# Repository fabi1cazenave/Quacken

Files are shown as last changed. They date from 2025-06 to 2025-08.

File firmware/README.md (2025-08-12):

# Firmware

## Keyberon

This directory contains our Keyberon driver. It’s been tested with a SparkFun
Pro Micro RP2040 and should be easy to adapt to other controllers.

To flash your keyboard, get in UF2 bootloader mode and do:

```rust
cargo run
```

If `elf2uf2-rs` does not work “as is” (see [this issue][1]), you can install a
patched version with:

```bash
cargo install --git https://github.com/StripedMonkey/elf2uf2-rs.git#c1638b9
```

## ZMK

[There is a ZMK Configuration on a dedicated repo][2].
It will be moved here when [this PR][3] gets merged.

[1]: https://github.com/JoNil/elf2uf2-rs/pull/41
[2]: https://github.com/Nuclear-Squid/zmk-keyboard-quacken
[3]: https://github.com/zmkfirmware/zmk/pull/2975

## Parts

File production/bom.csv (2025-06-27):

Designator | Footprint | Quantity | Value | LCSC Part #
D1, D10, D11, D12, D13, D14, D15, D16, D17, D18, D19, D2, D20, D21, D22, D23, D24, D25, D26, D27, D28, D29, D3, D30, D31, D32, D33, D34, D35, D36, D37, D38, D39, D4, D40, D41, D42, D5, D6, D7, D8, D9 | D_SOD-323 | 42

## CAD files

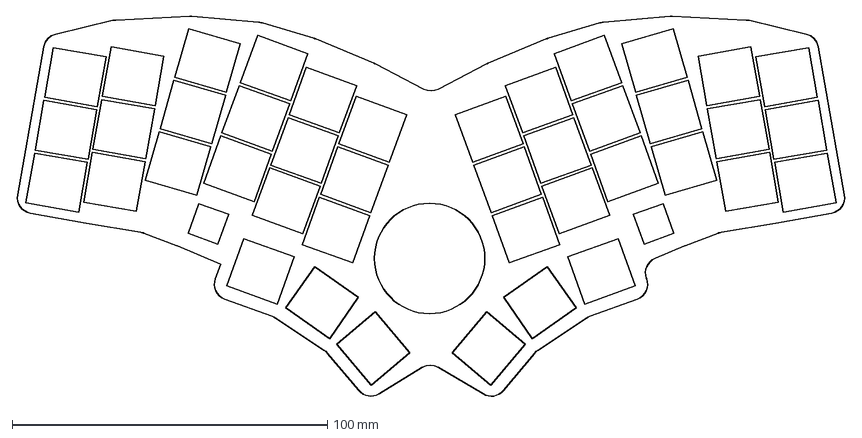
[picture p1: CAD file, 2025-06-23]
output/outlines/combo.dxf
263.0 x 121.1 mm

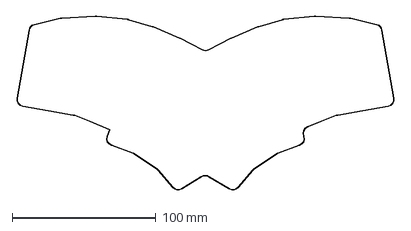
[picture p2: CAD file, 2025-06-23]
output/outlines/board.dxf
263.0 x 121.1 mm

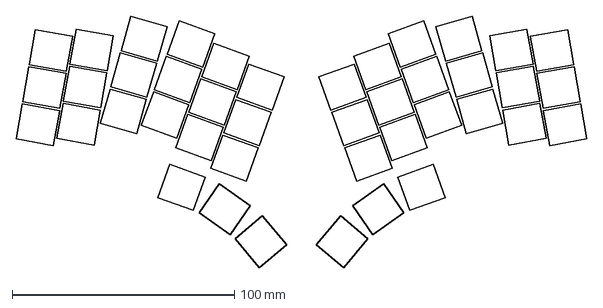
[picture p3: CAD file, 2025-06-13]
output/outlines/keys.dxf
256.9 x 113.0 mm

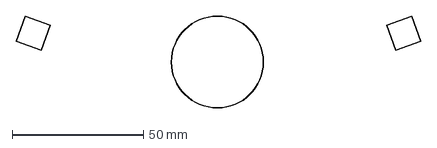
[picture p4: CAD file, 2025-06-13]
output/outlines/electronics.dxf
154.0 x 35.0 mm

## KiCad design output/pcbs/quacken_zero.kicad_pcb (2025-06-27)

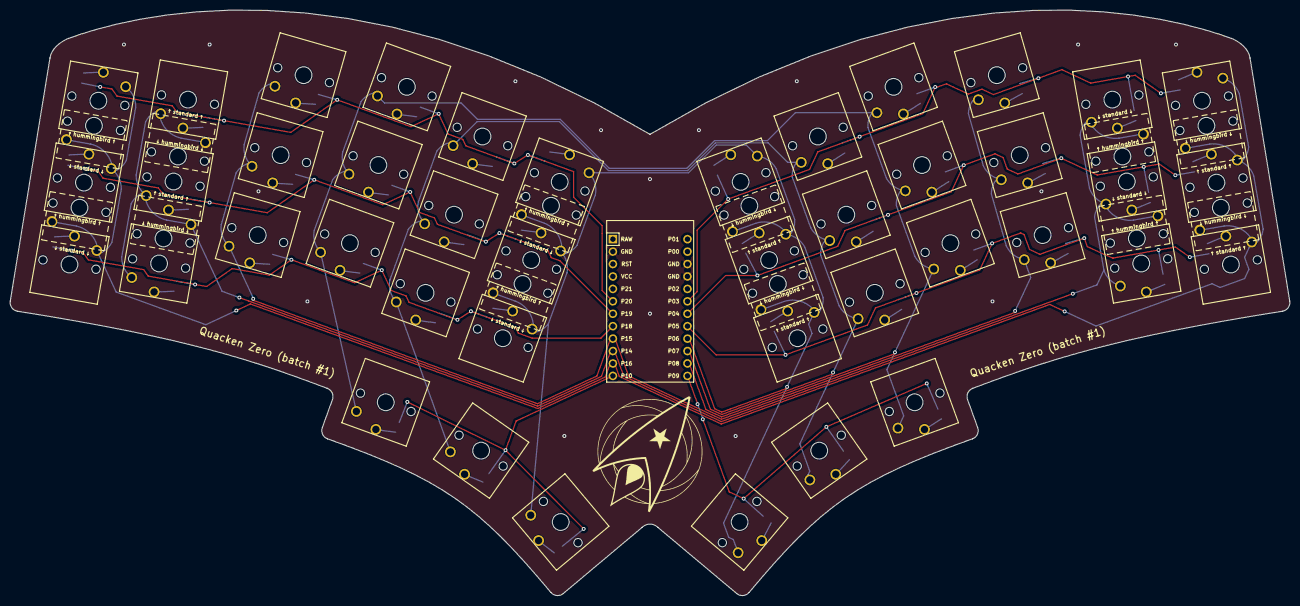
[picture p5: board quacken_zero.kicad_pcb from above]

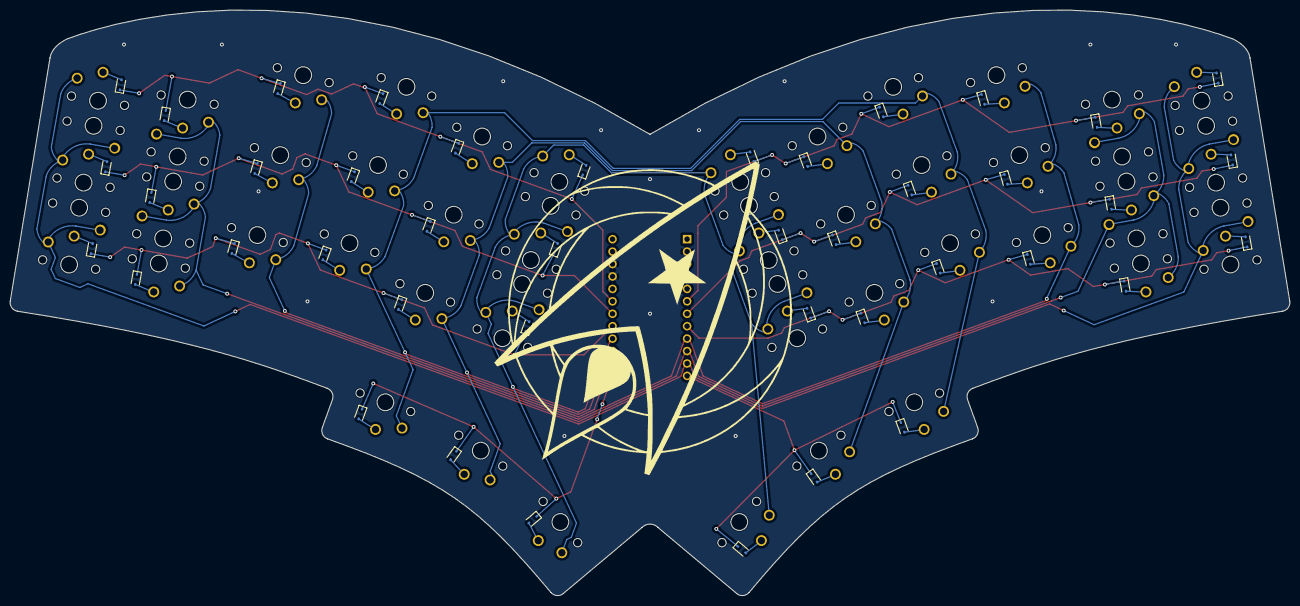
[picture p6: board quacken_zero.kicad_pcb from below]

Board: 2 copper layers, 261.5 x 119.6 mm, 85 parts (42 on the bottom side), 57 nets.

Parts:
D1, D2, D3, D4, D5, D6, D7, D8, D9, D10, D11, D12, D13, D14, D15, D16, D17, D18, D19, D20, D21, D22, D23, D24, D25, D26, D27, D28, D29, D30, D31, D32, D33, D34, D35, D36, D37, D38, D39, D40, D41, D42: D_SOD-323
MCU1: ProMicro
S1, S2, S3, S4, S5, S6, S7, S8, S9, S10, S11, S12, S13, S14, S15, S16, S17, S18, S19, S20, S21, S22, S23, S24, S25, S26, S27, S28, S29, S30, S31, S32, S33, S34, S35, S36, S37, S38, S39, S40, S41, S42: PG1350

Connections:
GND: MCU1.2, MCU1.15, MCU1.16
P3: D18.1, D21.1, D24.1, D27.1, D39.1, D42.1, MCU1.18
P4: D17.1, D20.1, D23.1, D26.1, D38.1, D41.1, MCU1.19
P5: D16.1, D19.1, D22.1, D25.1, D37.1, D40.1, MCU1.20
P6: MCU1.21, S15.1, S30.1, S34.1, S34.3, S35.1, S35.3, S36.1, S40.1, S40.3, S41.1, S41.3, S42.1
P7: MCU1.22, S10.1, S11.1, S12.1, S14.1, S25.1, S26.1, S27.1, S29.1
P8: MCU1.23, S7.1, S8.1, S9.1, S13.1, S22.1, S23.1, S24.1, S28.1
P9: D28.1, D29.1, D30.1, MCU1.24
P10: D13.1, D14.1, D15.1, MCU1.12
P14: MCU1.10, S1.1, S2.1, S2.3, S3.1, S3.3, S16.1, S17.1, S17.3, S18.1, S18.3
P15: MCU1.9, S4.1, S5.1, S6.1, S19.1, S20.1, S21.1
P16: MCU1.11, S31.1, S31.3, S32.1, S32.3, S33.1, S37.1, S37.3, S38.1, S38.3, S39.1
P18: D1.1, D4.1, D7.1, D10.1, D31.1, D34.1, MCU1.8
P19: D2.1, D5.1, D8.1, D11.1, D32.1, D35.1, MCU1.7
P20: D3.1, D6.1, D9.1, D12.1, D33.1, D36.1, MCU1.6
comfy_default: D14.2, S14.2
index_bottom: D10.2, S10.2
index_home: D11.2, S11.2
index_top: D12.2, S12.2
inner_bottom: D34.2, S34.2
inner_home: D35.2, S35.2
inner_top: D36.2, S36.2
middle_bottom: D7.2, S7.2
middle_home: D8.2, S8.2
middle_top: D9.2, S9.2
mirror_comfy_default: D29.2, S29.2
mirror_index_bottom: D25.2, S25.2
mirror_index_home: D26.2, S26.2
mirror_index_top: D27.2, S27.2
mirror_inner_bottom: D40.2, S40.2
mirror_inner_home: D41.2, S41.2
mirror_inner_top: D42.2, S42.2
mirror_middle_bottom: D22.2, S22.2
mirror_middle_home: D23.2, S23.2
mirror_middle_top: D24.2, S24.2
mirror_outer_bottom: D37.2, S37.2
mirror_outer_home: D38.2, S38.2
mirror_outer_top: D39.2, S39.2
mirror_pinky_bottom: D16.2, S16.2
mirror_pinky_home: D17.2, S17.2
mirror_pinky_top: D18.2, S18.2
mirror_reachy_default: D30.2, S30.2
mirror_ring_bottom: D19.2, S19.2
mirror_ring_home: D20.2, S20.2
mirror_ring_top: D21.2, S21.2
mirror_tucky_default: D28.2, S28.2
outer_bottom: D31.2, S31.2
outer_home: D32.2, S32.2
outer_top: D33.2, S33.2
pinky_bottom: D1.2, S1.2
pinky_home: D2.2, S2.2
pinky_top: D3.2, S3.2
reachy_default: D15.2, S15.2
ring_bottom: D4.2, S4.2
ring_home: D5.2, S5.2
ring_top: D6.2, S6.2
tucky_default: D13.2, S13.2

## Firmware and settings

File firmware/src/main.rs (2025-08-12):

#![no_std]
#![no_main]

mod layout; // 3*6 key layout
mod zero;   // QuackenZero-specific matrix scanning

// set the panic handler
use panic_halt as _;

#[unsafe(link_section = ".boot2")]
#[used]
pub static BOOT2: [u8; 256] = rp2040_boot2::BOOT_LOADER_W25Q080;

#[rtic::app(
    device = rp2040_hal::pac,
    peripherals = true,
    dispatchers = [PIO0_IRQ_0, PIO0_IRQ_1, PIO1_IRQ_0]
)]
mod app {
    use crate::layout::{self as kb_layout, QuackenLayout};
    use crate::zero::QuackenZeroMatrix;

    use core::convert::Infallible;

    use cortex_m::delay::Delay;

    use rp2040_hal::{
        self,
        Clock,
        clocks::init_clocks_and_plls,
        fugit::MicrosDurationU32,
        pac::CorePeripherals,
        gpio::Pins,
        sio::Sio,
        timer::{ Alarm, Alarm0, Timer },
        usb::UsbBus,
        watchdog::Watchdog,
    };

    use keyberon::{
        debounce::Debouncer,
        key_code::KbHidReport,
        layout::Layout,
    };

    use usb_device::{
        prelude::UsbDeviceState,
        class_prelude::UsbBusAllocator,
        // HACK: import the UsbClass trait, but still allow to use its name for a type later
        class::UsbClass as _,
    };

    type UsbClass = keyberon::Class<'static, UsbBus, ()>;
    type UsbDevice = usb_device::device::UsbDevice<'static, UsbBus>;

    trait ResultExt<T> {
        fn get(self) -> T;
    }
    impl<T> ResultExt<T> for Result<T, Infallible> {
        fn get(self) -> T {
            match self {
                Ok(v) => v,
                Err(e) => match e {},
            }
        }
    }

    // Fun fact: the keyboard is invisible to `lsusb`
    // if the scan time is set to 10_000 us or above.
    const SCAN_TIME_US:          u32 = 1_000;
    const WATCHDOG_TIME_US:      u32 = 10_000;
    const EXTERNAL_XTAL_FREQ_HZ: u32 = 12_000_000;

    #[shared]
    struct Shared {
        usb_dev: UsbDevice,
        usb_class: UsbClass,
        alarm: Alarm0,
        #[lock_free]
        watchdog: Watchdog,
    }

    #[local]
    struct Local {
        matrix: QuackenZeroMatrix,
        layout: QuackenLayout,
        debouncer: Debouncer<[[bool; kb_layout::COLS]; kb_layout::ROWS]>,
        delay: Delay,
        timer: Timer,
    }

    #[init(local = [bus: Option<UsbBusAllocator<UsbBus>> = None])]
    fn init(c: init::Context) -> (Shared, Local) {
        // https://github.com/rp-rs/rp-hal/blob/main/rp2040-hal-examples/src/bin/gpio_in_out.rs
        let mut resets = c.device.RESETS;
        let sio = Sio::new(c.device.SIO);
        let pins = Pins::new(
            c.device.IO_BANK0,
            c.device.PADS_BANK0,
            sio.gpio_bank0,
            &mut resets,
        );

        let mut watchdog = Watchdog::new(c.device.WATCHDOG);
        watchdog.pause_on_debug(false);

        let clocks = init_clocks_and_plls(
            EXTERNAL_XTAL_FREQ_HZ,
            c.device.XOSC,
            c.device.CLOCKS,
            c.device.PLL_SYS,
            c.device.PLL_USB,
            &mut resets,
            &mut watchdog,
        )
        .unwrap();

        let core = unsafe { CorePeripherals::steal() };
        let delay = Delay::new(core.SYST, clocks.system_clock.freq().to_Hz());

        let mut timer = Timer::new(c.device.TIMER, &mut resets, &clocks);
        let mut alarm = timer.alarm_0().unwrap();
        alarm
            .schedule(MicrosDurationU32::micros(SCAN_TIME_US))
            .expect("Couldn’t schedule matrix scan, kb is effectively bricked");
        alarm.enable_interrupt();

        let usb = UsbBus::new(
            c.device.USBCTRL_REGS,
            c.device.USBCTRL_DPRAM,
            clocks.usb_clock,
            true,
            &mut resets,
        );

        *c.local.bus = Some(UsbBusAllocator::new(usb));
        let usb_bus = c.local.bus.as_ref().unwrap();

        let usb_class = keyberon::new_class(usb_bus, ());
        let usb_dev = keyberon::new_device(usb_bus);

        watchdog.start(MicrosDurationU32::micros(WATCHDOG_TIME_US));

        let Ok(matrix) = QuackenZeroMatrix::new_sparkfun_rp2040(pins);

        (
            Shared {
                usb_dev,
                usb_class,
                alarm,
                watchdog,
            },
            Local {
                matrix,
                layout: Layout::new(&kb_layout::LAYERS),
                debouncer: Debouncer::new(
                    [[false; kb_layout::COLS]; kb_layout::ROWS],
                    [[false; kb_layout::COLS]; kb_layout::ROWS],
                    5
                ),
                delay,
                timer,
            },
        )
    }

    // USB events (polling)
    #[task(
        binds = USBCTRL_IRQ,
        priority = 4,
        shared = [usb_dev, usb_class]
    )]
    fn usb_rx(c: usb_rx::Context) {
        let usb = c.shared.usb_dev;
        let kb = c.shared.usb_class;
        (usb, kb).lock(|usb, kb| {
            if usb.poll(&mut [kb]) {
                kb.poll();
            }
        });
    }

    // keyboard events (timer)
    #[task(
        binds = TIMER_IRQ_0,
        priority = 1,
        local = [matrix, layout, debouncer, delay, timer],
        shared = [alarm, watchdog, usb_dev, usb_class],
    )]
    fn process_kbd_events(mut c: process_kbd_events::Context) {
        c.shared.alarm.lock(|a| {
            a.clear_interrupt();
            a.schedule(MicrosDurationU32::micros(SCAN_TIME_US))
                .expect("Couldn’t schedule matrix scan, kb is effectively bricked");
            a.enable_interrupt();
        });

        c.shared.watchdog.feed();

        let delay_1us = || { c.local.delay.delay_us(1) };
        for event in c.local.debouncer.events(c.local.matrix.get_with_delay(delay_1us).get()) {
            c.local.layout.event(event);
        }

        c.local.layout.tick();

        if c.shared.usb_dev.lock(|d| d.state()) != UsbDeviceState::Configured {
            return;
        }

        let report: KbHidReport = c.local.layout.keycodes().collect();
        if !c
            .shared
            .usb_class
            .lock(|k| k.device_mut().set_keyboard_report(report.clone()))
        {
            return;
        }

        while let Ok(0) = c.shared.usb_class.lock(|k| k.write(report.as_bytes())) {}
    }
}

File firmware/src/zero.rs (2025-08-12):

/**
The Quacken Zero physical matrix misses Keyberon's expectations on 2 points:
 - it doesn't match the logical layout
 - it is set col2row with pull-down inputs

Besides, the ProMicro GPIO pinout used by Ergogen and ZMK rely on the ProMicro Atmel IDs
-- but rb2040_hal, obviously, does not. So we need a Matrix factory for every ProMicro controller.

    .   +----USB----+               +----USB----+            D+ +----USB----+ D-
    . 1 |           | RAW         0 |           | RAW         1 |           | RAW
    . 0 |           | GND         1 |           | GND         0 |           | GND
    GND | SparkFun  | RST       GND | SparkFun  | RST       GND | Adafruit  | RST
    GND |   Atmel   | VCC       GND |  rp2040   | VCC       GND |  kb2040   | VCC
    . 2 |           | 21          2 |           | 29          2 |           | 29
    . 3 |           | 20          3 |           | 28          3 |           | 28
    . 4 |           | 19          4 |           | 27          4 |           | 27
    . 5 |           | 18          5 |           | 26          5 |           | 26
    . 6 |           | 15          6 |           | 22          6 |           | 18
    . 7 |           | 14          7 |           | 20          7 |           | 20
    . 8 |           | 16          8 |           | 23          8 |           | 19
    . 9 |___________| 10          9 |___________| 21          9 |___________| 10
**/

// The logical layout is a 12×4 matrix: 3×6 + 3 thumb keys for each hand.
// Ergogen has generated an 8*6 matrix rather than a 12×4 one, in order to save two pins:
// the two halves are stacked onto one anather. So here’s q quick helper to work around that.

use crate::layout;
const MATRIX_COLS: usize = 6;
const MATRIX_ROWS: usize = 8;

// this could be done with keyberon's debouncer (`transform` function)
fn matrix_to_layout(row: usize, col: usize) -> (usize, usize) {
    if row >= layout::ROWS {
        (row - layout::ROWS, layout::COLS - col - 1)
    } else {
        (row, col)
    }
}

// Keyberon expects rows to bo outputs, and columns to be pull-up inputs. ("row2col" on ZMK)
// On the Quacken Zero, rows are pull-down inputs and columns are outputs. ("col2row" on ZMK)
// So here's a `Col2RowMatrix` type to implement this.

// rp2040 implementations of the embedded_hal::digital::InputPin,OutputPin} traits
use rp2040_hal::gpio;
use embedded_hal::digital::{InputPin, OutputPin};
type KbInputPin  = gpio::Pin<gpio::DynPinId, gpio::FunctionSioInput,  gpio::PullDown>;
type KbOutputPin = gpio::Pin<gpio::DynPinId, gpio::FunctionSioOutput, gpio::PullDown>;

pub type QuackenZeroMatrix = Col2RowMatrix<KbOutputPin, KbInputPin>;

use core::convert::Infallible;

pub struct Col2RowMatrix<C, R>
where
    C: OutputPin,
    R: InputPin,
{
    cols: [C; MATRIX_COLS],
    rows: [R; MATRIX_ROWS],
}

impl<C, R> Col2RowMatrix<C, R>
where
    C: OutputPin,
    R: InputPin,
{
    /// Creates a new Matrix.
    ///
    /// Assumes rows are pull-down inputs, and columns are output pins
    /// which are set low when not being scanned.
    pub fn new<E>(cols: [C; MATRIX_COLS], rows: [R; MATRIX_ROWS]) -> Result<Self, E>
    where
        C: OutputPin<Error = E>,
        R: InputPin<Error = E>,
    {
        let mut res = Self { cols, rows };
        res.clear()?;
        Ok(res)
    }

    /// Clears the matrix.
    fn clear<E>(&mut self) -> Result<(), E>
    where
        C: OutputPin<Error = E>,
        R: InputPin<Error = E>,
    {
        for c in self.cols.iter_mut() {
            c.set_low()?;
        }
        Ok(())
    }

    /// Creates a new Generic FroMicro matrix.
    pub fn new_promicro(pins: gpio::Pins) -> Result<QuackenZeroMatrix, Infallible> {
        QuackenZeroMatrix::new(
            [
                pins.gpio8.into_push_pull_output().into_dyn_pin(),
                pins.gpio7.into_push_pull_output().into_dyn_pin(),
                pins.gpio6.into_push_pull_output().into_dyn_pin(),
                pins.gpio16.into_push_pull_output().into_dyn_pin(),
                pins.gpio14.into_push_pull_output().into_dyn_pin(),
                pins.gpio15.into_push_pull_output().into_dyn_pin(),
            ],
            [
                pins.gpio3.into_pull_down_input().into_dyn_pin(),
                pins.gpio4.into_pull_down_input().into_dyn_pin(),
                pins.gpio5.into_pull_down_input().into_dyn_pin(),
                pins.gpio9.into_pull_down_input().into_dyn_pin(),
                pins.gpio20.into_pull_down_input().into_dyn_pin(),
                pins.gpio19.into_pull_down_input().into_dyn_pin(),
                pins.gpio18.into_pull_down_input().into_dyn_pin(),
                pins.gpio10.into_pull_down_input().into_dyn_pin(),
            ],
        )
    }

    /// Creates a new SparkFun ProMicro RP2040 matrix.
    pub fn new_sparkfun_rp2040(pins: gpio::Pins) -> Result<QuackenZeroMatrix, Infallible> {
        QuackenZeroMatrix::new(
            [
                pins.gpio8.into_push_pull_output().into_dyn_pin(),
                pins.gpio7.into_push_pull_output().into_dyn_pin(),
                pins.gpio6.into_push_pull_output().into_dyn_pin(),
                pins.gpio23.into_push_pull_output().into_dyn_pin(), // promicro 16
                pins.gpio20.into_push_pull_output().into_dyn_pin(), // promicro 14
                pins.gpio22.into_push_pull_output().into_dyn_pin(), // promicro 15
            ],
            [
                pins.gpio3.into_pull_down_input().into_dyn_pin(),
                pins.gpio4.into_pull_down_input().into_dyn_pin(),
                pins.gpio5.into_pull_down_input().into_dyn_pin(),
                pins.gpio9.into_pull_down_input().into_dyn_pin(),
                pins.gpio28.into_pull_down_input().into_dyn_pin(),  // promicro 20
                pins.gpio27.into_pull_down_input().into_dyn_pin(),  // promicro 19
                pins.gpio26.into_pull_down_input().into_dyn_pin(),  // promicro 18
                pins.gpio21.into_pull_down_input().into_dyn_pin(),  // promicro 10
            ],
        )
    }

    /// Scans the matrix and checks which keys are pressed.
    ///
    /// Every column pin in order is pulled high, and then each row pin is tested:
    /// if it's high, the key is marked as pressed.
    ///
    /// Delay function allows pause to let input pins settle.
    pub fn get_with_delay<F: FnMut(), E>(&mut self, mut delay: F)
        -> Result<[[bool; layout::COLS]; layout::ROWS], E>
    where
        C: OutputPin<Error = E>,
        R: InputPin<Error = E>,
    {
        let mut keys = [[false; layout::COLS]; layout::ROWS];
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

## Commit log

2025-06-13 Initial commit: semi-minimalist keyboard.
    [board.dxf, combo.dxf, electronics.dxf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]
2025-06-15 Added gerbers archive.
2025-06-23 Put capacitors on bottom side + better hotswap.
    [board.dxf, combo.dxf, quacken_pcb.kicad_pcb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]
2025-06-23 Reorganised repo.
    [bom.csv, designators.csv, positions.csv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]
2025-06-27 First batch of Quacken Zero!
    [bom.csv, freerouting.dsn, positions.csv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]
2025-07-12 Add pcb images
    To actually see what we are talking about
2025-07-24 quick SVG mock-up (with magic numbers) (#2)
    * quick SVG mock-up (with magic numbers)
    * gémétrie calquée sur Ergogen
    * deux piafs de plus
    * page web + selecteur
    * typos
    * Align geometry on KiCad outputs
    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
2025-08-12 keyberon firmware (#3)
    * (wip) keyberon firmware
    * credentials
    * Updated `.gitignore` file.
    * credentials
    * Fixed compilation errors related to usb.
    * wip: switch to the latest rp2040_hal API
    * 12*4 => 8*6 grid
    * low-hanging fruits (warnings)
    * proper type casting for gpio pins
    * proper build target
    * basic keyboard layout
    * Fixed linking error: necessary features on crate `rp2040-hal`.
    * Fixed firmware upload script.
    * RP2040 chip is now recognised as a USB peripheral.
    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
    [main.rs, zero.rs]
